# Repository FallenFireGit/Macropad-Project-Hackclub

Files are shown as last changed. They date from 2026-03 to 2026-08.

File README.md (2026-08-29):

# Macropad-Project-Hackclub

This project is a fully custom macropad created as part of Hack Club’s Blueprint program. It includes hardware design, firmware development, and key mapping to streamline workflows for coding, media control, and everyday tasks.

<br/>

## Final Design

<br/>



<br/>

## Schematic (Not the greatest schematic OAT, but it works)

<br/>



<br/>

## PCB

<br/>



<br/>

## Exploded View

Do note that the PCB is connected to the plate via an M2 screw (needed to be small to fit between switches), which screws into the plastic on the bottom plate. Since the switches are soldered to the PCB, the top plate is secured by being sandwiched between the MX switches and then the bottom plate. (The little red part for the OLED is held together with friction with the pins on the OLED. Once I actually get it, I will superglue it or use AMS in later revisions.)

<br/>



<br/>

## BOM

* 1x SEEEDUINO XIAO RP2040
* 4x MX Cherry Style switches
* 4x DSA Keycaps
* 1x EC11 Rotary Encoder
* 1x 0.91-inch OLED display
* 5x 1N4148 diodes
* 1x M2 Screw

## Firmware

The macropad runs [KMK](https://github.com/KMKfw/kmk_firmware) on CircuitPython. The board mounts as a USB drive, so edits take effect on save -- no toolchain, no compiling, no reflashing.

Four MX switches across two layers:

| Switch | Programming | CAD |
| --- | --- | --- |
| Top middle | `UP` | Ctrl+Z undo |
| Bottom middle | `DOWN` | Ctrl+Y redo |
| Bottom left | `LEFT` | `ESC` |
| Bottom right | `RIGHT` | `ENTER` |

The rotary encoder does triple duty:

| Encoder | Action |
| --- | --- |
| Turn | Volume, or menu navigation when a menu is open |
| Single click | Play / pause |
| Double click | Open the menu |

The menu holds a layer picker, a 25-minute Pomodoro timer, and a USB power indicator. Whenever nothing else needs the screen, the OLED loops a fire animation.

Pinout, install steps, and how to remap keys: [Firmware/circuitpython/README.md](Firmware/circuitpython/README.md)

<br/>

## Changing the OLED animation

[OLED Studio](Tools/README.md) turns any GIF or image into the format the display reads and copies it onto the board:

```bash
python Tools/oled_studio.py
```

Open a GIF, drag the threshold slider until the live preview looks right, then press **Send to macropad**. There is a command-line mode for scripting:

```bash
python Tools/oled_studio.py fire.gif --size 32x32 --dither --send
```

Needs Python 3.10+ and Pillow (`pip install pillow`).

<br/>

## Repository layout

| Path | Contents |
| --- | --- |
| `PCB/` | KiCad schematic and board layout |
| `CAD/` | Case model |
| `Production/` | Gerbers and printable plates |
| `Firmware/circuitpython/` | The firmware running on the board, and its animation |
| `Tools/` | OLED Studio, the animation uploader |

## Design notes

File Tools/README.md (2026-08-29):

# OLED Studio

Turn any image or GIF into an animation on the macropad's OLED, without
hand-editing byte arrays.

## Setup

You need Python 3.10 or newer and Pillow:

```bash
pip install pillow
```

## Using the app

```bash
python Tools/oled_studio.py
```

1. **Open image or GIF** — pick anything: a GIF, a PNG, a photo.
2. Choose the frame size. `32x32` is the sprite size the fire animation uses;
   `128x32` fills the whole 0.91" display.
3. Adjust **Threshold** until the preview looks right. The preview animates at
   roughly the speed the board will play it.
   - **Dither** works better for photos and gradients.
   - **Pixel art** turns off smoothing, for art drawn at small sizes.
   - **Fit mode** controls what happens when the source is not square:
     `fit` letterboxes, `stretch` distorts to fill, `crop` fills and trims.
4. **Send to macropad** with the board plugged in, or **Save .bmp...** to keep
   the file.

The board reloads on its own once the file lands, so the new animation plays
within a second or two.

## Using it from the command line

Handy for batching or for rebuilding an animation from a script:

```bash
python Tools/oled_studio.py fire.gif -o anim.bmp --size 32x32 --dither --send
```

| Flag | Meaning |
| --- | --- |
| `-o, --output` | Where to write the `.bmp` (defaults next to the input) |
| `--size` | Frame size, e.g. `32x32` or `128x32` |
| `--threshold` | Black/white cutoff, 0–255 (default 128) |
| `--dither` | Dither instead of a hard cutoff |
| `--invert` | Swap black and white |
| `--scaling` | `fit`, `stretch`, or `crop` |
| `--pixel-art` | Resize without smoothing |
| `--send` | Also copy onto a plugged-in board |

## The file format

The firmware reads one BMP holding every frame stacked vertically:

- **1 bit per pixel**, two-entry palette — index 0 black, index 1 white
- **Bottom-up** row order (positive height in the DIB header)
- Rows padded to 4-byte boundaries, as the BMP spec requires
- Sheet height is `frame_height x frame_count`

This is byte-for-byte the layout the original hand-written `make_fire.py`
produced, so animations made before this tool existed still work. That
compatibility is verified: encoding the frames of the original `anim.bmp`
through this tool reproduces the file exactly, hash for hash.

## Tests

```bash
cd Tools && python -m unittest test_oled_bmp -v
```

24 tests cover the header fields, row padding at awkward widths, frame
ordering (the check that catches an upside-down animation), threshold and
invert behaviour, and reading multi-frame GIFs.

## Finding the board

The uploader looks for `boot_out.txt` in the root of every mounted drive
rather than matching the `CIRCUITPY` volume label, so a renamed drive still
works. If the board is not detected, press **Rescan for board** — and check
that it is running CircuitPython rather than sitting in bootloader mode,
where it mounts as `RPI-RP2` instead.

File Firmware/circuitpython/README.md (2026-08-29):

# KMK firmware

The CircuitPython firmware running on the macropad. `code.py` here is a copy
of what is on the board — captured from a working unit, not written from the
schematic.

Tested on **Adafruit CircuitPython 10.2.1**, Seeeduino XIAO RP2040.

**Maintainer:** [Conner Hopkins](https://github.com/FallenFireGit)
**Hardware:** Seeed XIAO RP2040, 4x MX switches, EC11 rotary encoder, 0.91"
SSD1306 OLED
**Parts:** [Seeed Studio](https://www.seeedstudio.com/),
[Mechanical Keyboards](https://mechanicalkeyboards.com/)

## Pinout

Matches `PCB/Macropad_Project.kicad_pcb`:

| Function | Pins |
| --- | --- |
| Matrix rows | D0, D1 |
| Matrix columns | D2, D3 |
| Encoder rotation | D8 (A), D7 (B) |
| Encoder push | D9 strobed against row D0 |
| OLED I²C | `board.I2C()` — D4 = SDA, D5 = SCL, address `0x3C` |

Diode orientation is `COL2ROW`.

### Why the encoder button is handled by hand

The encoder's push switch sits in the matrix at row D0 / column D9, but D9 is
**not** passed to `MatrixScanner`. Instead `SmartSystem._read_button()`
strobes it directly:

```python
self.row0_pin.switch_to_input(pull=digitalio.Pull.UP)
self.d9.value = False
pressed = not self.row0_pin.value
self.d9.value = True
self.row0_pin.switch_to_output(value=True)
```

That keeps the button out of the keymap so it can drive the menu system —
single click and double click mean different things depending on state,
which a plain keycode could not express.

## Key layout

```
        [encoder]   [SW2]
    [SW3]   [SW4]   [SW5]
```

Scan order is row-major over rows × columns, and `coord_mapping = [0, 1, 2, 3]`
keeps it as-is:

| Index | Row/Col | Switch | Layer 0 "Programming" | Layer 1 "CAD" |
| --- | --- | --- | --- | --- |
| 0 | D0/D2 | SW2 (top middle) | `UP` | Ctrl+Z undo |
| 1 | D0/D3 | SW4 (bottom middle) | `DOWN` | Ctrl+Y redo |
| 2 | D1/D2 | SW3 (bottom left) | `LEFT` | `ESC` |
| 3 | D1/D3 | SW5 (bottom right) | `RIGHT` | `ENTER` |

## Encoder and menu

| Action | Effect |
| --- | --- |
| Turn | Volume up / down (navigates when a menu is open) |
| Single click | Play / pause |
| Double click | Open the menu |

Menu options: **Choose Layer**, **Start Pomodoro** (25 minutes), **Toggle
USB** (shows `[USB]` or `[PWR]`), **Exit**. Turn to move, click to select.

While the menu, Pomodoro timer, or layer picker is showing, the display
swaps the animation out for text and back again when it returns to normal.

## Display

`displayio.OnDiskBitmap` streams `anim.bmp` from the drive rather than
loading it into RAM — worth it on a board with about 600 KB free. A strict
two-colour palette is forced on top, which is what fixed the all-black
screen.

The sprite is 32×32 drawn at `x = 48`, centred on the 128×32 panel, and
advances every 42 ms.

If `anim.bmp` is missing, the firmware falls back to an ASCII blink
animation rather than failing to boot.

## Changing the animation

Use `Tools/oled_studio.py` — open a GIF, tune the preview, press **Send to
macropad**. It writes exactly the format this firmware expects: 1-bit,
bottom-up, 32×32 frames stacked vertically.

That compatibility is verified rather than assumed. The `anim.bmp` committed
here is the file running on the board, and it is byte-identical to what OLED
Studio produces — same SHA-256.

## Installing on a fresh board

1. Flash CircuitPython for the **Seeed XIAO RP2040** from
   [circuitpython.org](https://circuitpython.org/board/seeeduino_xiao_rp2040/).
   Double-tap reset for `RPI-RP2`, drop the `.uf2` on, wait for `CIRCUITPY`.
2. Copy `code.py` and `anim.bmp` to the root of the drive.
3. Populate `lib/` exactly as the board has it:

```
CIRCUITPY/
├── code.py
├── anim.bmp
└── lib/
    ├── kmk/                          <- KMK firmware, note: inside lib/
    ├── adafruit_bus_device/
    ├── adafruit_display_text/
    ├── adafruit_displayio_ssd1306.mpy
    └── adafruit_ticks.mpy
```

`kmk/` goes **inside `lib/`**, not at the drive root.

No `adafruit_imageload` is needed — `displayio.OnDiskBitmap` is built into
CircuitPython.

## Housekeeping

The drive is only about 1 MB. Worth keeping off it:

- `.idea/` — JetBrains project metadata, roughly 13 KB, written there if the
  board is opened as a project folder
- `sd/placeholder.txt` — unused

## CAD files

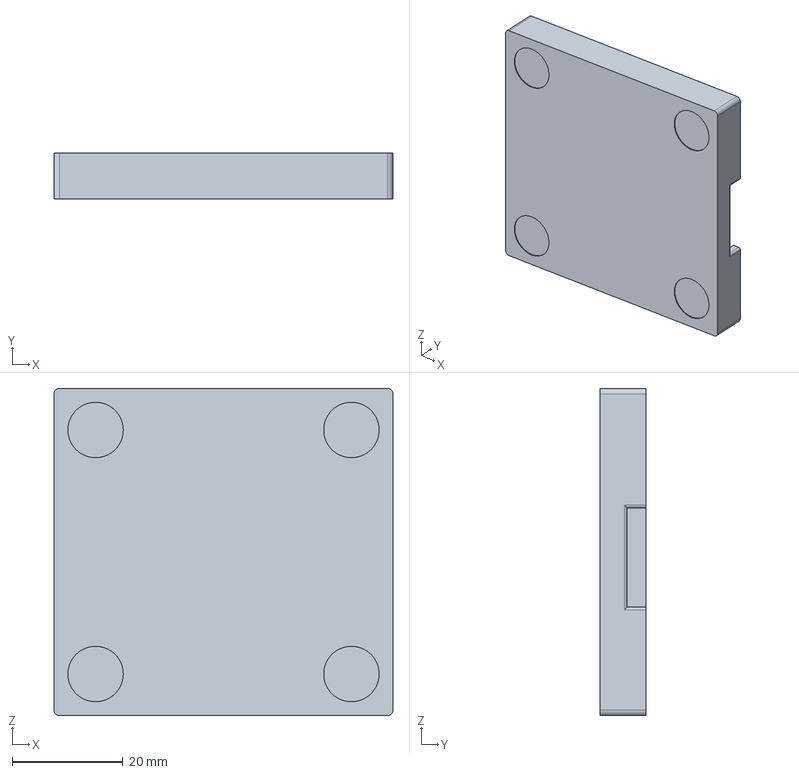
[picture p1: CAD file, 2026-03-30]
Production/Bottom Plate.step
61.2 x 8.38 x 59.0 mm

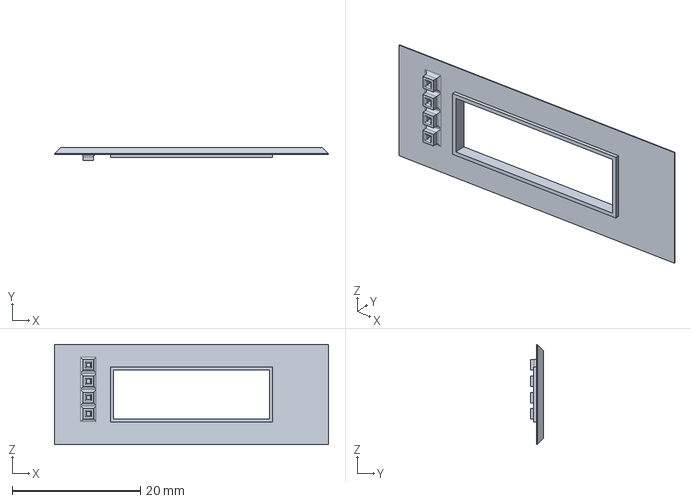
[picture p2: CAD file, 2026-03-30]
Production/OLED Plate.step
42.8 x 2.10 x 15.6 mm

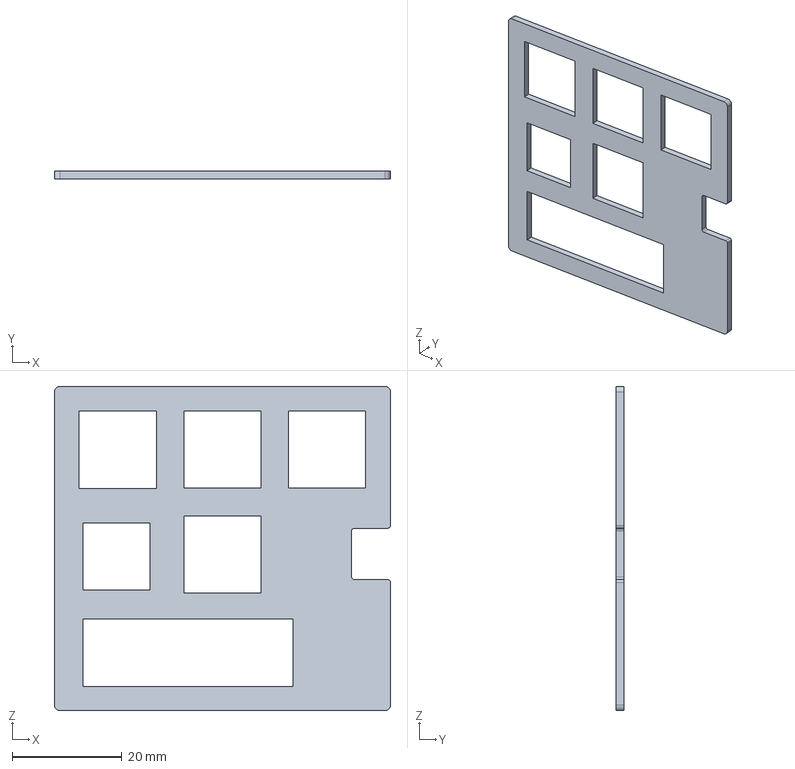
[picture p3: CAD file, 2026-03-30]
Production/Top Plate.step
61.2 x 1.50 x 59.0 mm

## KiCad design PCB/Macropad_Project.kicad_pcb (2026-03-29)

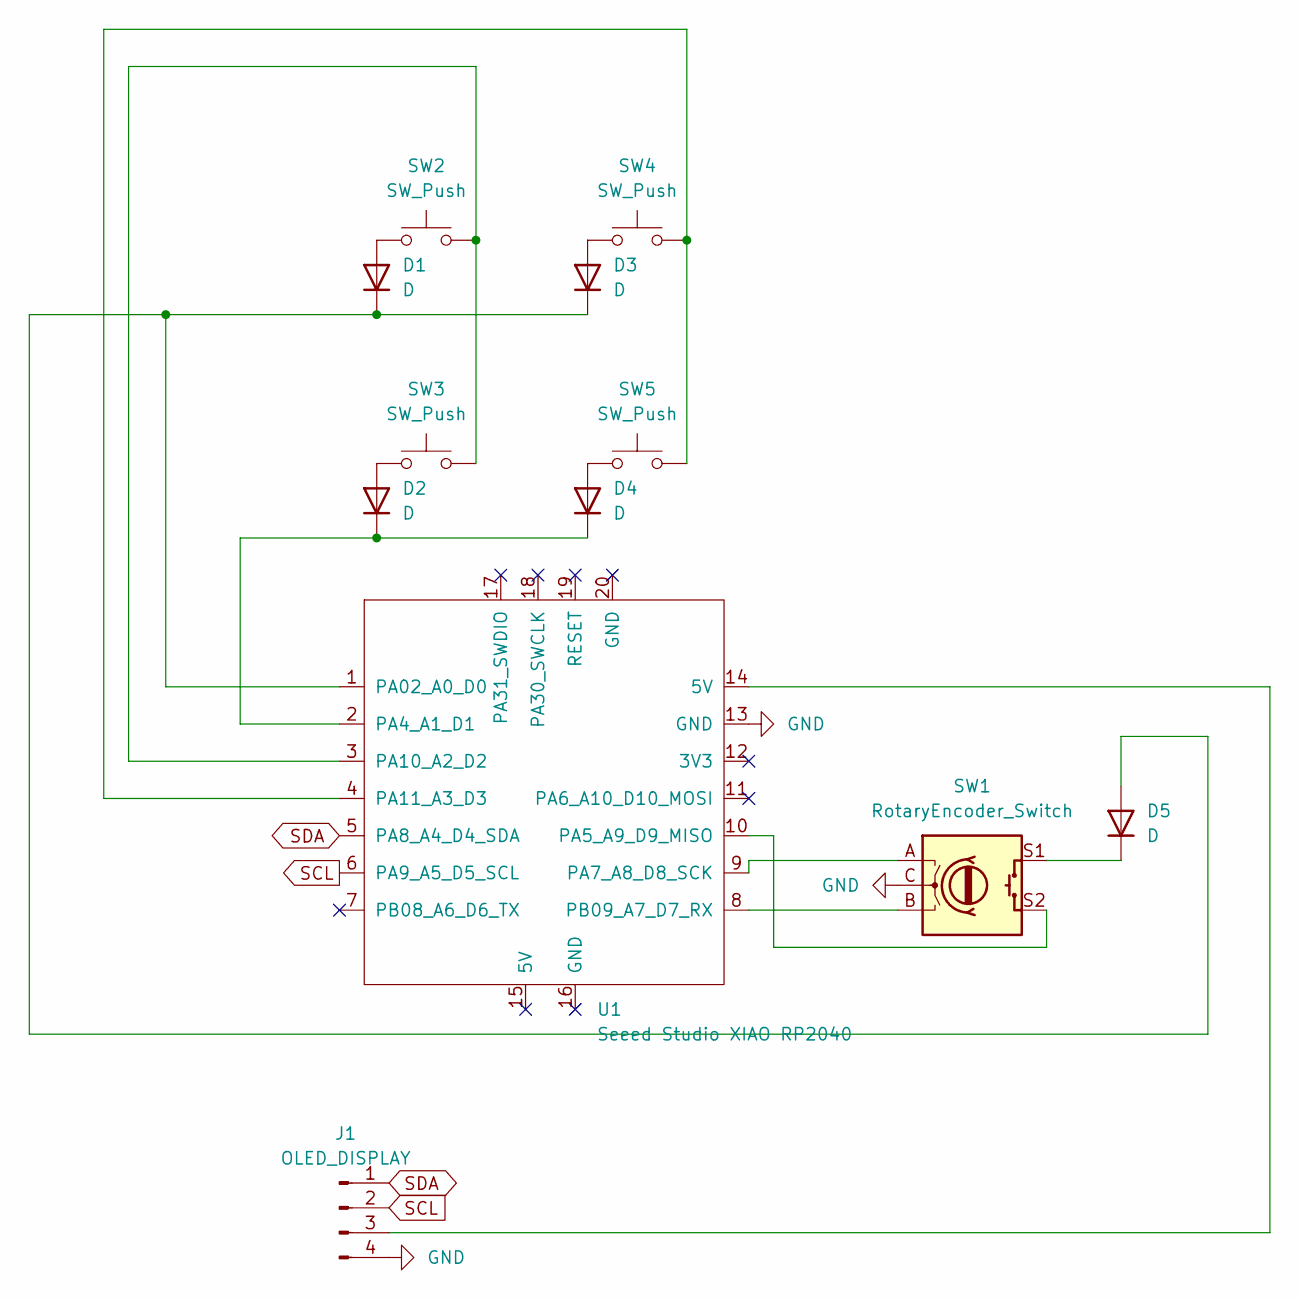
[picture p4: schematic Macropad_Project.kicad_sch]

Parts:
D1, D2, D3, D4, D5: D; D_DO-35_SOD27_P7.62mm_Horizontal
J1: OLED_DISPLAY; PinHeader_1x04_P2.54mm_Vertical
SW1: RotaryEncoder_Switch; RotaryEncoder_Alps_EC11E-Switch_Vertical_H20mm
SW2, SW3, SW4, SW5: SW_Push; MX-Solderable-1U
U1: Seeed Studio XIAO RP2040; XIAO-Generic-Hybrid-14P-2.54-21X17.8MM

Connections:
GND: J1.4, SW1.C, U1.13 (GND)
unnamed: D1.2 (A), SW2.1
unnamed: D1.1 (K), D3.1 (K), D5.2 (A), U1.1 (PA02_A0_D0)
unnamed: D2.2 (A), SW3.1
unnamed: D2.1 (K), D4.1 (K), U1.2 (PA4_A1_D1)
unnamed: D3.2 (A), SW4.1
unnamed: D4.2 (A), SW5.1
unnamed: D5.1 (K), SW1.S1
unnamed: J1.3, U1.14 (5V)
unnamed: SW1.S2, U1.10 (PA5_A9_D9_MISO)
unnamed: SW1.A, U1.9 (PA7_A8_D8_SCK)
unnamed: SW2.2, SW3.2, U1.3 (PA10_A2_D2)
unnamed: SW4.2, SW5.2, U1.4 (PA11_A3_D3)
unnamed: SW1.B, U1.8 (PB09_A7_D7_RX)
SCL: J1.2, U1.6 (PA9_A5_D5_SCL)
SDA: J1.1, U1.5 (PA8_A4_D4_SDA)

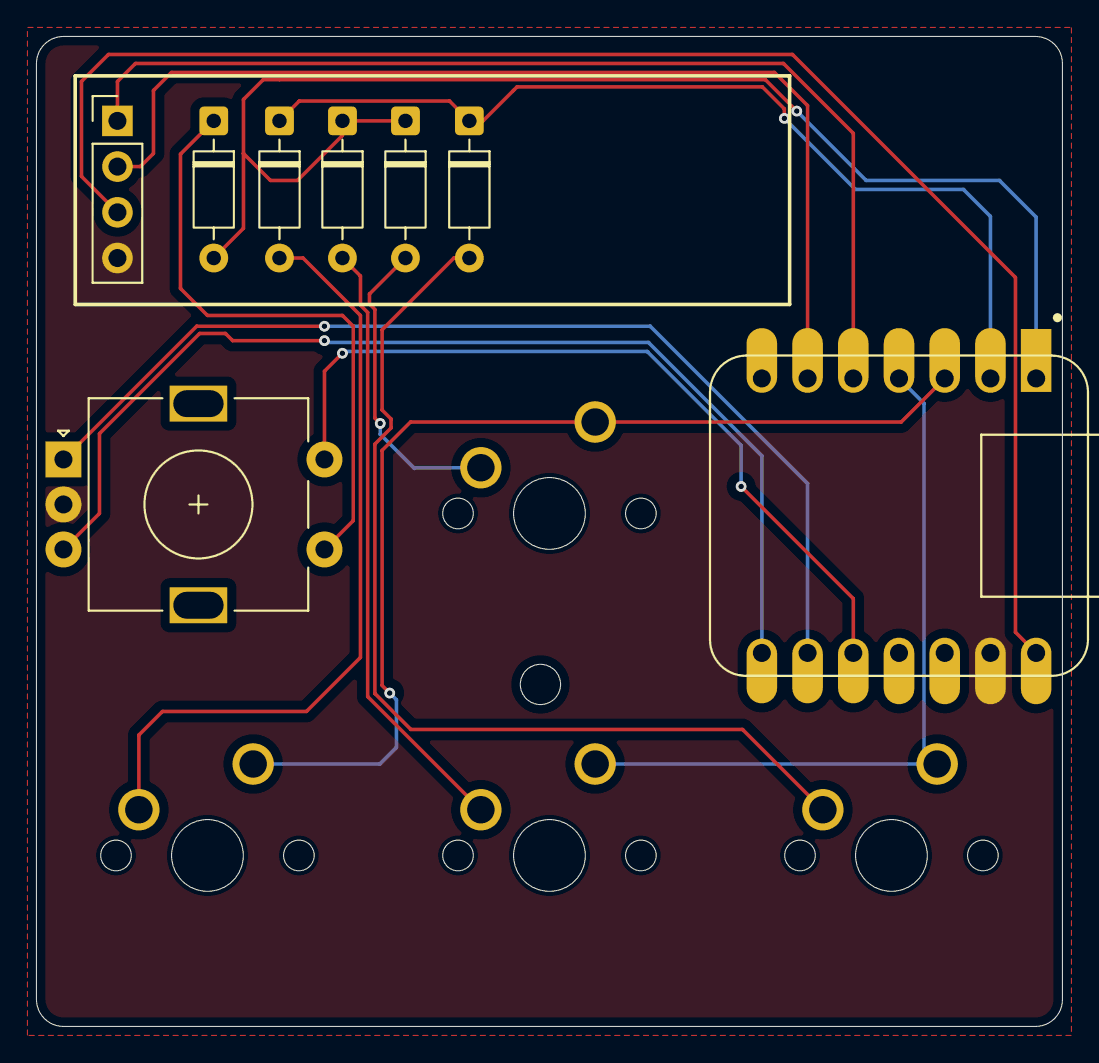
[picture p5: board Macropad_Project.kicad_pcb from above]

Board: 2 copper layers, 57.0 x 55.0 mm, 12 parts (0 on the bottom side), 16 nets.

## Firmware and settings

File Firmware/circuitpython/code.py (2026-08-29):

import time
import board
import digitalio
import displayio
import i2cdisplaybus
import terminalio
import json
import supervisor
from adafruit_display_text import bitmap_label

from kmk.kmk_keyboard import KMKKeyboard
from kmk.keys import KC, make_key, ConsumerKey
from kmk.scanners import DiodeOrientation
from kmk.scanners.digitalio import MatrixScanner
from kmk.modules import Module
from kmk.modules.encoder import EncoderHandler
from kmk.modules.layers import Layers

# ---------------------------------------------------------------------------
# 1. KEYBOARD CORE & LAYERS
# ---------------------------------------------------------------------------
keyboard = KMKKeyboard()
keyboard.debug_enabled = True

keyboard.matrix = MatrixScanner(
    cols=[board.D2, board.D3],
    rows=[board.D0, board.D1],
    diode_orientation=DiodeOrientation.COL2ROW,
)
keyboard.coord_mapping = [0, 1, 2, 3]

encoders = EncoderHandler()
layers = Layers()
keyboard.modules.append(encoders)
keyboard.modules.append(layers)

encoders.pins = ((board.D8, board.D7, None, False),)

make_key(names=('VOLU',), constructor=ConsumerKey, code=0xE9)
make_key(names=('VOLD',), constructor=ConsumerKey, code=0xEA)
make_key(names=('MPLY',), constructor=ConsumerKey, code=0xCD)

# --- LAYERS ---
L0_PROGRAMMING = [KC.UP, KC.DOWN, KC.LEFT, KC.RIGHT]
L1_CAD = [KC.LCTRL(KC.Z), KC.LCTRL(KC.Y), KC.ESC, KC.ENTER]

keyboard.keymap = [L0_PROGRAMMING, L1_CAD]
LAYER_NAMES = ["Programming", "CAD"]

VOLUME_ENCODER_MAP = [((KC.VOLU, KC.VOLD, KC.NO),)]
encoders.map = VOLUME_ENCODER_MAP

# ---------------------------------------------------------------------------
# 2. DISPLAY SETUP & BITMAP LOADER
# ---------------------------------------------------------------------------
displayio.release_displays()
i2c = board.I2C()
display_bus = i2cdisplaybus.I2CDisplayBus(i2c, device_address=0x3C)

import adafruit_displayio_ssd1306
display = adafruit_displayio_ssd1306.SSD1306(display_bus, width=128, height=32)

main_group = displayio.Group()

has_bmp = False
try:
    sprite_sheet = displayio.OnDiskBitmap("/anim.bmp")
    
    # Force a strict 2-color palette to fix the black screen bug
    palette = displayio.Palette(2)
    palette[0] = 0x000000 # Black
    palette[1] = 0xFFFFFF # White

    sprite = displayio.TileGrid(
        sprite_sheet, 
        pixel_shader=palette,
        width=1, height=1, 
        tile_width=32, tile_height=32
    )
    sprite.x = 48 # Centered on a 128px wide screen
    sprite.y = 0
    main_group.append(sprite)
    bmp_frames = sprite_sheet.height // 32 
    has_bmp = True
    print(f"Loaded anim.bmp! Found {bmp_frames} frames.")
except Exception as e:
    print(f"Failed to load anim.bmp: {e}")

line1 = bitmap_label.Label(terminalio.FONT, text="Booting...", x=4, y=8)
line2 = bitmap_label.Label(terminalio.FONT, text="", x=4, y=22)

if not has_bmp:
    main_group.append(line1)
    main_group.append(line2)

display.root_group = main_group

ANIMATIONS = {"blink": ["(o_o)", "(-_-)", "(o_o)", "(^_^)"]}
ANIMATION_FRAME_MS = 42 

# ---------------------------------------------------------------------------
# 3. MENU / POMODORO / SYSTEM MODULE
# ---------------------------------------------------------------------------
STATE_NORMAL = "NORMAL"
STATE_MENU = "MENU"
STATE_POMODORO = "POMODORO"
STATE_PICK_LAYER = "PICK_LAYER"

MENU_OPTIONS = ["Choose Layer", "Start Pomodoro", "Toggle USB", "Exit"]

class SmartSystem(Module):
    def __init__(self):
        self.state = STATE_NORMAL
        self.menu_index = 0
        self.layer_pick_index = 0
        self.show_usb_info = False 
        self.current_layer = 0

        self.anim_frame_index = 0
        self._last_anim_time = time.monotonic()
        
        self.pomo_end_time = 0

        self._button_last = True
        self._last_press_time = None
        self._pending_single = False
        self._pending_single_time = 0
        self._last_scan = time.monotonic()

        self.d9 = digitalio.DigitalInOut(board.D9)
        self.d9.direction = digitalio.Direction.OUTPUT
        self.d9.value = True 
        self.row0_pin = None 
        self._dirty = True

    def during_bootup(self, keyboard):
        self.row0_pin = keyboard.matrix[0].outputs[0]

    def before_matrix_scan(self, keyboard):
        now = time.monotonic()
        if now - self._last_scan < 0.02:  
            return
        self._last_scan = now

        pressed = self._read_button()
        if pressed and self._button_last:
            self._on_button_down(keyboard, now)
        self._button_last = not pressed

        if self._pending_single and (now - self._pending_single_time) > 0.35:
            self._pending_single = False
            self._fire_single_click(keyboard)

        # Continuous Animation Loop
        if self.state == STATE_NORMAL:
            if has_bmp:
                if (now - self._last_anim_time) > (ANIMATION_FRAME_MS / 1000):
                    self._last_anim_time = now
                    self.anim_frame_index = (self.anim_frame_index + 1) % bmp_frames
                    sprite[0] = self.anim_frame_index
            else:
                if (now - self._last_anim_time) > (400 / 1000):
                    self._last_anim_time = now
                    frames = ANIMATIONS["blink"]
                    self.anim_frame_index = (self.anim_frame_index + 1) % len(frames)
                    self._dirty = True

        if self._dirty:
            self._render(now)
            self._dirty = False

    def after_matrix_scan(self, keyboard): return
    def before_hid_send(self, keyboard): return
    def after_hid_send(self, keyboard): return
    def on_powersave_enable(self, keyboard): return
    def on_powersave_disable(self, keyboard): return
    def process_key(self, keyboard, key, is_pressed, int_coord): return key

    def _read_button(self):
        self.row0_pin.switch_to_input(pull=digitalio.Pull.UP)
        self.d9.value = False
        pressed = not self.row0_pin.value
        self.d9.value = True
        self.row0_pin.switch_to_output(value=True)
        return pressed

    def _on_button_down(self, keyboard, now):
        if self._last_press_time is not None and (now - self._last_press_time) < 0.35:
            self._pending_single = False
            self._last_press_time = None
            self._fire_double_click(keyboard)
        else:
            self._last_press_time = now
            self._pending_single = True
            self._pending_single_time = now
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

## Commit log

2026-03-29 Create Macropad-Blueprint-CAD
2026-03-30 Rename Bottom Plate.step to Production/Bottom Plate.step
    [Bottom Plate.step]
2026-03-30 Rename OLED Plate.step to Production/OLED Plate.step
    [OLED Plate.step]
2026-03-30 Rename Top Plate.step to Production/Top Plate.step
    [Top Plate.step]
2026-08-28 docs: flatten README section headings to a consistent level (#1)
    Final Design, Schematic, PCB, Exploded View, and BOM are sibling
    sections, but each was nested one level deeper than the last, ending
    at h6. GitHub renders h6 smaller than surrounding body text, so the
    BOM heading appeared as the least prominent text in the file.
    Set all five to h2 and drop a trailing space after "Exploded View".
    Content is unchanged.
2026-08-29 feat: add OLED Studio for uploading animations without editing code (#3)
    Updating the OLED animation previously meant hand-writing byte arrays,
    as make_fire.py did with its inline frame data. OLED Studio replaces
    that with a GUI: open a GIF or image, tune the threshold against a live
    animated preview, and send it straight to the board.
    The output format matches make_fire.py byte for byte, so animations
    built before this tool still load. Verified by re-encoding the frames
    of the original anim.bmp and comparing hashes.
    Includes a CLI mode for scripting and 24 unit tests covering header
    fields, 4-byte row padding, bottom-up frame ordering, threshold/invert
    behaviour, and multi-frame GIF handl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
2026-08-29 feat: add the working KMK firmware from the board (#5)
    * feat: add KMK firmware matching the traced PCB pinout
    Pins come from PCB/Macropad_Project.kicad_pcb rather than assumption:
    rows D0/D1, cols D2/D3/D9, COL2ROW, encoder rotation on D8/D7 with its
    push switch inside the matrix at row D0 / col D9 through diode D5.
    That in-matrix push switch is why EncoderHandler gets None for its
    button pin, and why coord_mapping is [2, 0, 3, 1, 4] -- it reorders the
    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
2026-08-29 chore: remove the QMK config and its build, which could never have run (#6)
    * chore: remove the QMK config, which could never have run
    info.json assigns the matrix and encoder to GP8, GP9, and GP10. The
    Seeeduino XIAO RP2040 does not break those pins out -- it exposes GP0-GP4,
    GP6, GP7, and GP26-GP29 -- so this configuration could not have worked on
    any build of this board.
    The macropad runs KMK, and the firmware it actually runs is now in the
    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
2026-08-29 docs: document the firmware and animation tooling in the README (#7)
    The README covered the hardware -- renders, schematic, PCB, exploded
    view, BOM -- but stopped there, so nothing explained what the macropad
    does once it is built or how to change what the OLED shows.
    Adds three sections after the BOM: what the firmware does (keymap,
    encoder, menu), how to swap the OLED animation with OLED Studio, and a
    table of where things live in the repo.
    Existing content, images, and wording are untouched; this is additions
    only.
